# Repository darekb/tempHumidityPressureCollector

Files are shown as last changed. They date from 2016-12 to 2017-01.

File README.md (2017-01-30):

# tempHumidityPressureCollector
part of WatherStationProject
Get data from BME280, convert to readable data and send via RF module to laptop with RF recivier module connect by Arduino Duemilanove.

## Part list:

* BME280 Temperature Humidity Pressure Sensor
* RF module 433.92MHz
* Atmega328A-PU
* 16MHz oscilator
* 100nF capacitors
* 22nF capacitors
* 4.7μF capacitors
* LF33CV3 linear voltage regulator
* some wires and connectors :)

## Software:

* Pure C code (measure fired by 8bit timer)
* adapted library: [https://github.com/cosminp12/BME280-Weather-Station](https://github.com/cosminp12/BME280-Weather-Station)
* adapted from arduino version (Mike McCauley library VirtualWire): [VirtualWire API documentation and download instructions](http://www.airspayce.com/mikem/arduino/VirtualWire/index.html)

## Status

Working library BME280
Working RF module 433.92MHz library (VirtualWire from arduino)

##Next step
Add function to sleeping microcontroller between measurement.

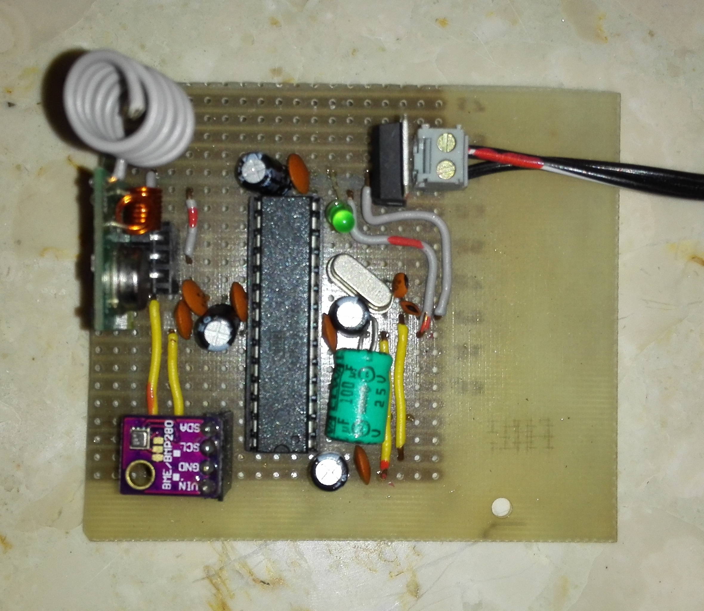
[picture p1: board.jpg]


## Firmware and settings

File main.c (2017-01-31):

#include <avr/io.h>
#include <avr/interrupt.h>
#include <util/delay.h>
#include <stdlib.h>
#include <stdio.h>
#include <string.h>

#ifndef F_CPU
#define F_CPU 16000000UL
#endif

#define showDebugDataMain 1

#include "main.h"
#include "slI2C.h"

#if showDebugDataMain == 1
#include "slUart.h"
#endif

#include "BME280.h"
#include "VirtualWire.h"

//TODO 1. wgrać do innego uC wsad z nasłuchiwaniem RF module 433.92MHz
//TODO 2. wywalać do uart surowe wartości
//TODO 3. wymienić uC na ten zaprogramowany przezemnie
//TODO 4. merge to master (WIN!!!)

//deploy checklist
//1. ustawić showDebugDataMain na 0
//2. ustawić w bibliotekach logowanie na 0
//3. usunąć z CMakeLists.txt slUart.c

#define LED (1 << PB0)
#define LED_TOG PORTB ^= LED
#define DELIMITER "|"

float temperature, humidity, pressure;
char req[39] = "";
char buf[VW_MAX_MESSAGE_LEN];
char buflen = VW_MAX_MESSAGE_LEN;
char wiad[39] = "";
volatile uint8_t stage = 0;
volatile uint16_t counter = 0;

void toStringToSend(float inData, char *out) {
  char bufor[10] = "";
  strcat(out, DELIMITER);
  dtostrf((float) inData, 1, 2, bufor);
  strcat(out, bufor);
}

uint8_t stage1_SetBME280Mode() {
  if (BME280_SetMode(BME280_MODE_FORCED)) {
#if showDebugDataMain == 1
    slUART_WriteString("Sensor set forced mode error!\r\n");
#endif
    return 1;
  }
  return 0;
}

uint8_t stage2_GetDataFromBME280() {
  if (BME280_ReadAll(&temperature, &pressure, &humidity)) {
#if showDebugDataMain == 1
    slUART_WriteString("Sensor read error!\r\n");
#endif
    return 1;
  }
  return 0;
}

uint8_t stage3_prepareDataToSend() {
  strcpy(req, "");
  //temperature
  toStringToSend(temperature, req);
  //humidity
  toStringToSend(humidity, req);
  //pressure
  toStringToSend(pressure, req);
  //vcc
  //float vcc = 0.0;
  //toStringToSend(vcc, req);
  //sensor nr an char endig transmission
  strcat(req, "|11|z");
  return 0;
}

uint8_t stage4_sendViaRadio() {
  LED_TOG;
  //strcpy(req, "|25.89|43.58|102410.00|z");
  vw_send((uint8_t *) req, strlen(req));
  vw_wait_tx(); // Wait until the whole message is gone
#if showDebugDataMain == 1
  slUART_WriteString("Send value: ");
  slUART_WriteString(req);
  slUART_WriteString("\r\n");
#endif
  LED_TOG;
  return 0;
}


int main(void) {
  TCCR0B |= (1 << CS02) | (1 << CS00);//prescaler 1024
  TIMSK0 |= (1 << TOIE0);//przerwanie przy przepłnieniu timera0

  DDRB |= LED;

  slI2C_Init();

#if showDebugDataMain == 1
  slUART_SimpleTransmitInit();
#endif

  vw_setup(2000);   // Bits per sec
  //vw_tx_start();//przestować czy będzie działać
  sei();

#if showDebugDataMain == 1
  slUART_WriteString("Start.\r\n");
#endif
  if (BME280_Init(BME280_OS_T_1, BME280_OS_P_1, BME280_OS_H_1, BME280_FILTER_OFF, BME280_MODE_FORCED,
                  BME280_TSB_1000)) {
#if showDebugDataMain == 1
    slUART_WriteString("BMP280 init error.\r\n");
#endif
  } else {
#if showDebugDataMain == 1
    slUART_WriteString("BMP280 init done.\r\n");
#endif
  }
  while (1) {
    switch (stage) {
      case 1:
        if (stage1_SetBME280Mode()) {
          stage = 0;
          return 1;
        }
        stage = 2;
        break;
      case 2:
        if (stage2_GetDataFromBME280()) {
          stage = 0;
          return 1;
        }
        stage = 3;
        break;
      case 3:
        if (stage3_prepareDataToSend()) {
          stage = 0;
          return 1;
        }
        stage = 4;
        break;
      case 4:
        if (stage4_sendViaRadio()) {
          stage = 0;
          return 1;
        }
        stage = 0;
        break;
    }
  }
  return 0;
}

ISR(TIMER0_OVF_vect) {
  //co 0.01632sek.
  counter = counter + 1;
  if (counter == 1224) {//9.98784x2 sek
    counter = 0;
    if(stage == 0){
      stage = 1;
    }
  }
}

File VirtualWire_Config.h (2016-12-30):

#ifndef VirtualWire_Config_h
#define VirtualWire_Config_h
//////////////////////////////////////////////////////////////////////////
//	The following configurations are intented only if VW_PLATFORM == VW_PLATFORM_GENERIC_AVR8

//	Uncomment this to select the platform as generic AVR8
#define VW_PLATFORM VW_PLATFORM_GENERIC_AVR8

//	OPTIONAL: Define the IO pin used for PTT (push to talk)
//	If no PTT port will be defined, the PTT feature will be disabled
//#define VW_PTT_PORT PORT#
//#define VW_PTT_DDR  DDR#
//#define VW_PTT_PIN  PIN#?

// Define the IO pin used for transmitting data
#define VW_TX_PORT PORTB
#define VW_TX_DDR  DDRB
#define VW_TX_PIN  PINB5

// Define the IO pin used for receiving data
#define VW_RX_PORT  PORTB
#define VW_RX_DDR  DDRB
#define VW_RX_PIN  PINB1

//	Define the 16 bits timer index to be used by the library (e.g. 1)
//	The default timer configuration will use TIMSKn as interrupt mask register,
//     OCRnA as compare register and TIMERn_COMPA_vect as interrupt vector
//	If one of the above doesn't suite your current platform, please redefine
//     the timer setup routine, as indicated below
//#define VW_TIMER_INDEX 1

//	Select Timer 1 as the 16 bits timer used by the library
#define VW_TIMER_INDEX 1

//
//	EXAMPLE: configuration suitable for At90USB162 or ATMega32U2
//

/*
	//	Select AVR8 platform
	#define VW_PLATFORM VW_PLATFORM_GENERIC_AVR8
	
	//	My radio doesn't have PTT feature => VW_PTT_PORT/DDR/PIN will be left undefined
	//#define VW_PTT_PORT
	//#define VW_PTT_DDR
	//#define VW_PTT_PIN

	//	VirtualWire TX
	#define VW_TX_PORT PORTD
	#define VW_TX_DDR  DDRD
	#define VW_TX_PIN  PIND7

	//	VirtualWire RX
	#define VW_RX_PORT PIND
	#define VW_RX_DDR  DDRD
	#define VW_RX_PIN  PIND6

	//	Reduce message length, saves up memory
	#define VW_MAX_MESSAGE_LEN 40

	//	Select Timer 1 as the 16 bits timer used by the library
	#define VW_TIMER_INDEX 1
*/

//
//	OPTIONAL: Alternative pin setup for advanced configurations
//	Instead of defining VW_PTT_PORT/DDR/PIN, VW_TX_PORT/DDR/PIN or VW_RX_PORT/DDR/PIN
//	   the user can use the following preprocessor directives to control the way
//	   VirtualWire library reads the RX and writes to the TX or PTT
//

//#define vw_pinSetup()
//#define vw_digitalWrite_ptt(value) 
//#define vw_digitalRead_rx()
//#define vw_digitalWrite_tx(value)

//
//	EXAMPLE: Advanced pin configuration that lights up a LED when PTT is high
//           RX=PORTD7, PTT=PORTD6, LED=PORTD5, TX=PORTD4
//

/*
	//	Select AVR8 platform
	#define VW_PLATFORM VW_PLATFORM_GENERIC_AVR8

	#define vw_pinSetup()\
			DDRD |=  (1<<PORTD6)|(1<<PORTD5)|(1<<PORTD4);\
			DDRD &= ~(1<<PORTD7);

	#define vw_digitalWrite_ptt(value)\
		((value)? PORTD |= (1<<PORTD6)|(1<<PORTD5) : PORTD &= ~((1<<PORTD6)|(1<<PORTD5))
	#define vw_digitalRead_rx() \
		(PORTD & (1<<PORTD7) ? 1 : 0)
	#define vw_digitalWrite_tx(value) \
		((value) ? PORTD |= (1<<PORTD4) : PORTD &= ~(1<<PORTD4))
*/

//
//	OPTIONAL: Alternative timer configuration
//	If the default timer setup doesn't suite the platform you are using, you can
//	   rewrite the timer setup routine and define the timer vector used by the ISR
//	   implemented within the library
//

//#define vw_timerSetup(speed)
//#define VW_TIMER_VECTOR

//
//	EXAMPLE: Setting up a user defined timer configuration for VirtualWire
//			 that uses OCR1B as compare register instead of OCR1A
//

/*
	#include <stdint.h>

	//	Select AVR8 platform
	#define VW_PLATFORM VW_PLATFORM_GENERIC_AVR8

	//	Declare my own timer setup function
	static inline void my_vw_timerSetup(uint8_t speed) __attribute__ ((always_inline));

	//	VirtualWire has a special routine for detecting prescaler and the number of ticks
	//	   automatically, but needs to be declared first in order to be used
	uint8_t vw_timer_calc(uint16_t speed, uint16_t max_ticks, uint16_t *nticks);

	//	Instruct VirtualWire to use my timer setup routine and my interrupt vector
	#define vw_timerSetup(speed) my_vw_timerSetup(speed);
	#define VW_TIMER_VECTOR TIMER1_COMPB_vect

	//	Define my setup timer routine, that uses OCR1B as compare register
	static inline void my_vw_timerSetup(uint8_t speed)
	{
		// Figure out prescaler value and counter match value
		prescaler = vw_timer_calc(speed, (uint16_t)-1, &nticks);
		if (!prescaler)
		{
			return; // fault
		}

		TCCR1A = 0; // Output Compare pins disconnected
		TCCR1B = _BV(WGM12); // Turn on CTC mode

		// Convert prescaler index to TCCR1B prescaler bits CS10, CS11, CS12
		TCCR1B |= prescaler;

		// Caution: special procedures for setting 16 bit regs
		// is handled by the compiler
		OCR1B = nticks;	
		
		//	Enable interrupt
		TIMSK1 |= _BV(OCIE1B);
	}
*/

#endif /* VirtualWire_Config_h */

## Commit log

2016-10-03 arduino version complete
2016-10-04 fix uart library for atmega328
    [main.c]
2016-10-04 with Bosch Sensortec library (too large)
    [main.c]
2016-10-05 czange BME280 lib like Arduino lib
2016-10-05 fixed version with updated slI2C and BME280 version
    [BME280.c, main.c, slI2C.c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]
2016-10-06 add debug uart code to BME280 lib and slI2C
2016-10-06 addcatch error return from slI2C library function
    [BME280.c, slI2C.c, slI2C.h]
2016-10-10 update functions BME280_CompensateH, BME280_CompensateP, BME280_CompensateT to Bosch Sensortec code
2016-10-11 working with new calculate tem, hum, and pressure, calculations from Bosch Sensortec, but humidity is completly random
2016-10-18 BME280_CompensateP return float value
    [tempHumidityPressureCollector.fzz]
2016-10-18 remove cat type from calibration in BME280_Init
2016-10-18 fix BME280_init and slI2C.c
    [BME280.c, slI2C.c, slI2C.h]
2016-10-27 add function toStringToSend();
    [tempHumidityPressureCollector.fzz]
2016-10-27 update virtualWire lib and making strong from sensor data got to extrnal function
2016-10-28 add timer interrupt way to application structure
2016-11-03 add condition stage ==0 in ISR (main.c)
2017-01-30 add real foto of board
